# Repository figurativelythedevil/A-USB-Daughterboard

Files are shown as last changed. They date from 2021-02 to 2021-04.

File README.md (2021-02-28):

A work in progress.

This is a USB-C daughterboard for keyboards with a 4-port USB 2.0 hub on it (2 USB-A, 2 internal facing connectors on JST SR connectors), based around the Microchip USB2514 IC. 

Many thanks to:
* The [C3 Unified Daughterboard](https://github.com/ai03-2725/Unified-Daughterboard) project, form which this daughterboard was based off of 
* The [Nanohub Project](https://hackaday.io/project/20790-nanohub-tiny-usb-20-and-30-hubs) - the USB2514 schematic was partially referenced off of the 4-port USB 2.0 design 

This is available open-source under the CERN OHL-W license and uses the [Acheron library](https://github.com/AcheronProject/AcheronLibrary). 

This project has not been tested yet.

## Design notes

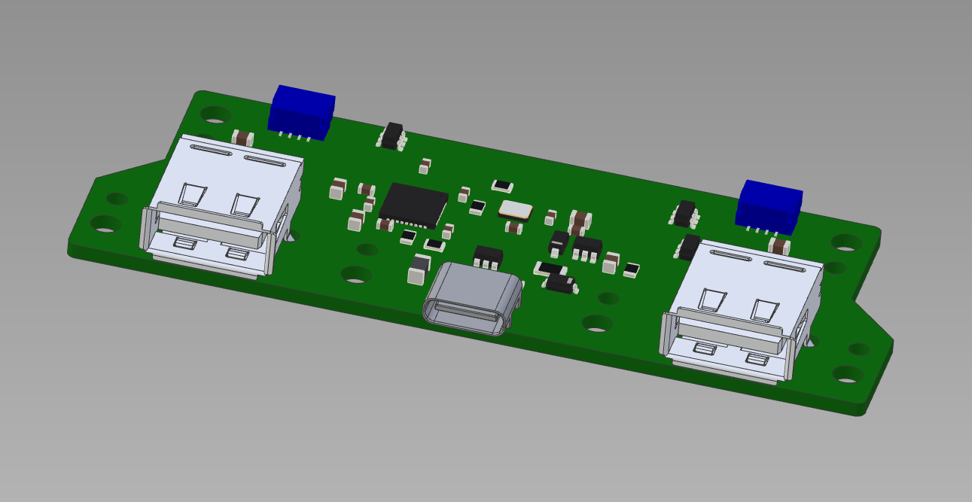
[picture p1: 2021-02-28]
3D-picture.PNG

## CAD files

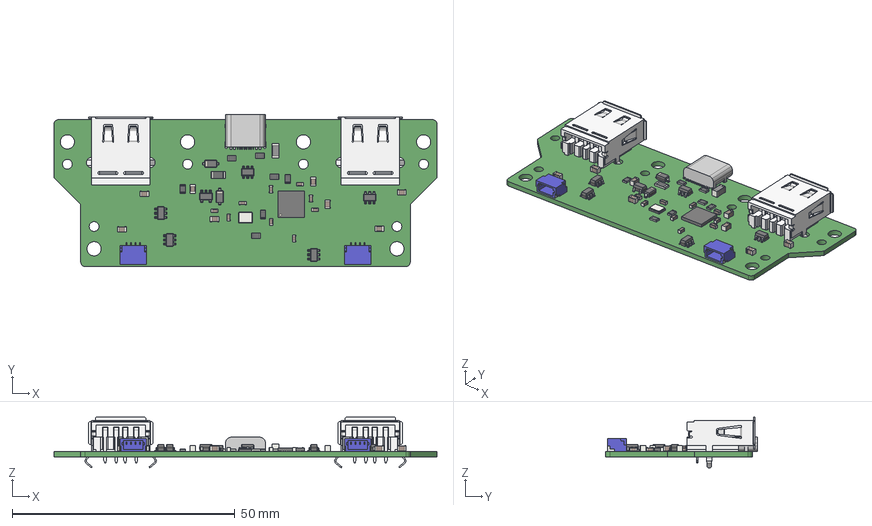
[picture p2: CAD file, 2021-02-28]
A-USB-daughterboard.stp
86.0 x 34.2 x 11.4 mm

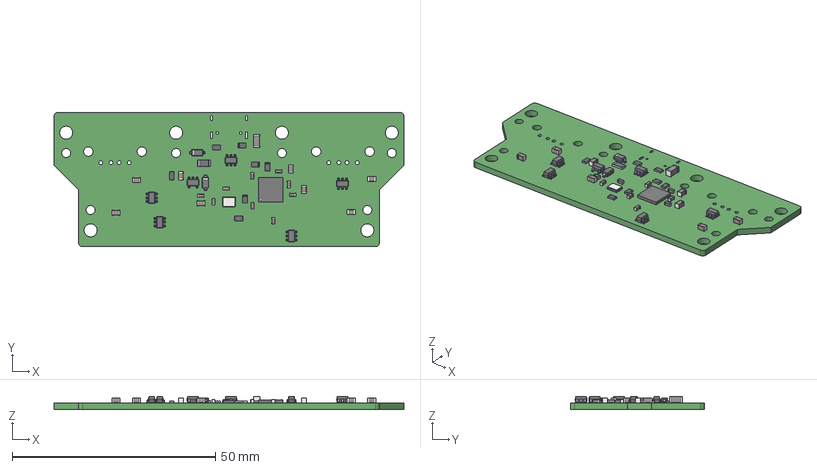
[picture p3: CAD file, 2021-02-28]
KiCAD files/USB-hub-daughterboard.step
86.0 x 33.0 x 3.25 mm

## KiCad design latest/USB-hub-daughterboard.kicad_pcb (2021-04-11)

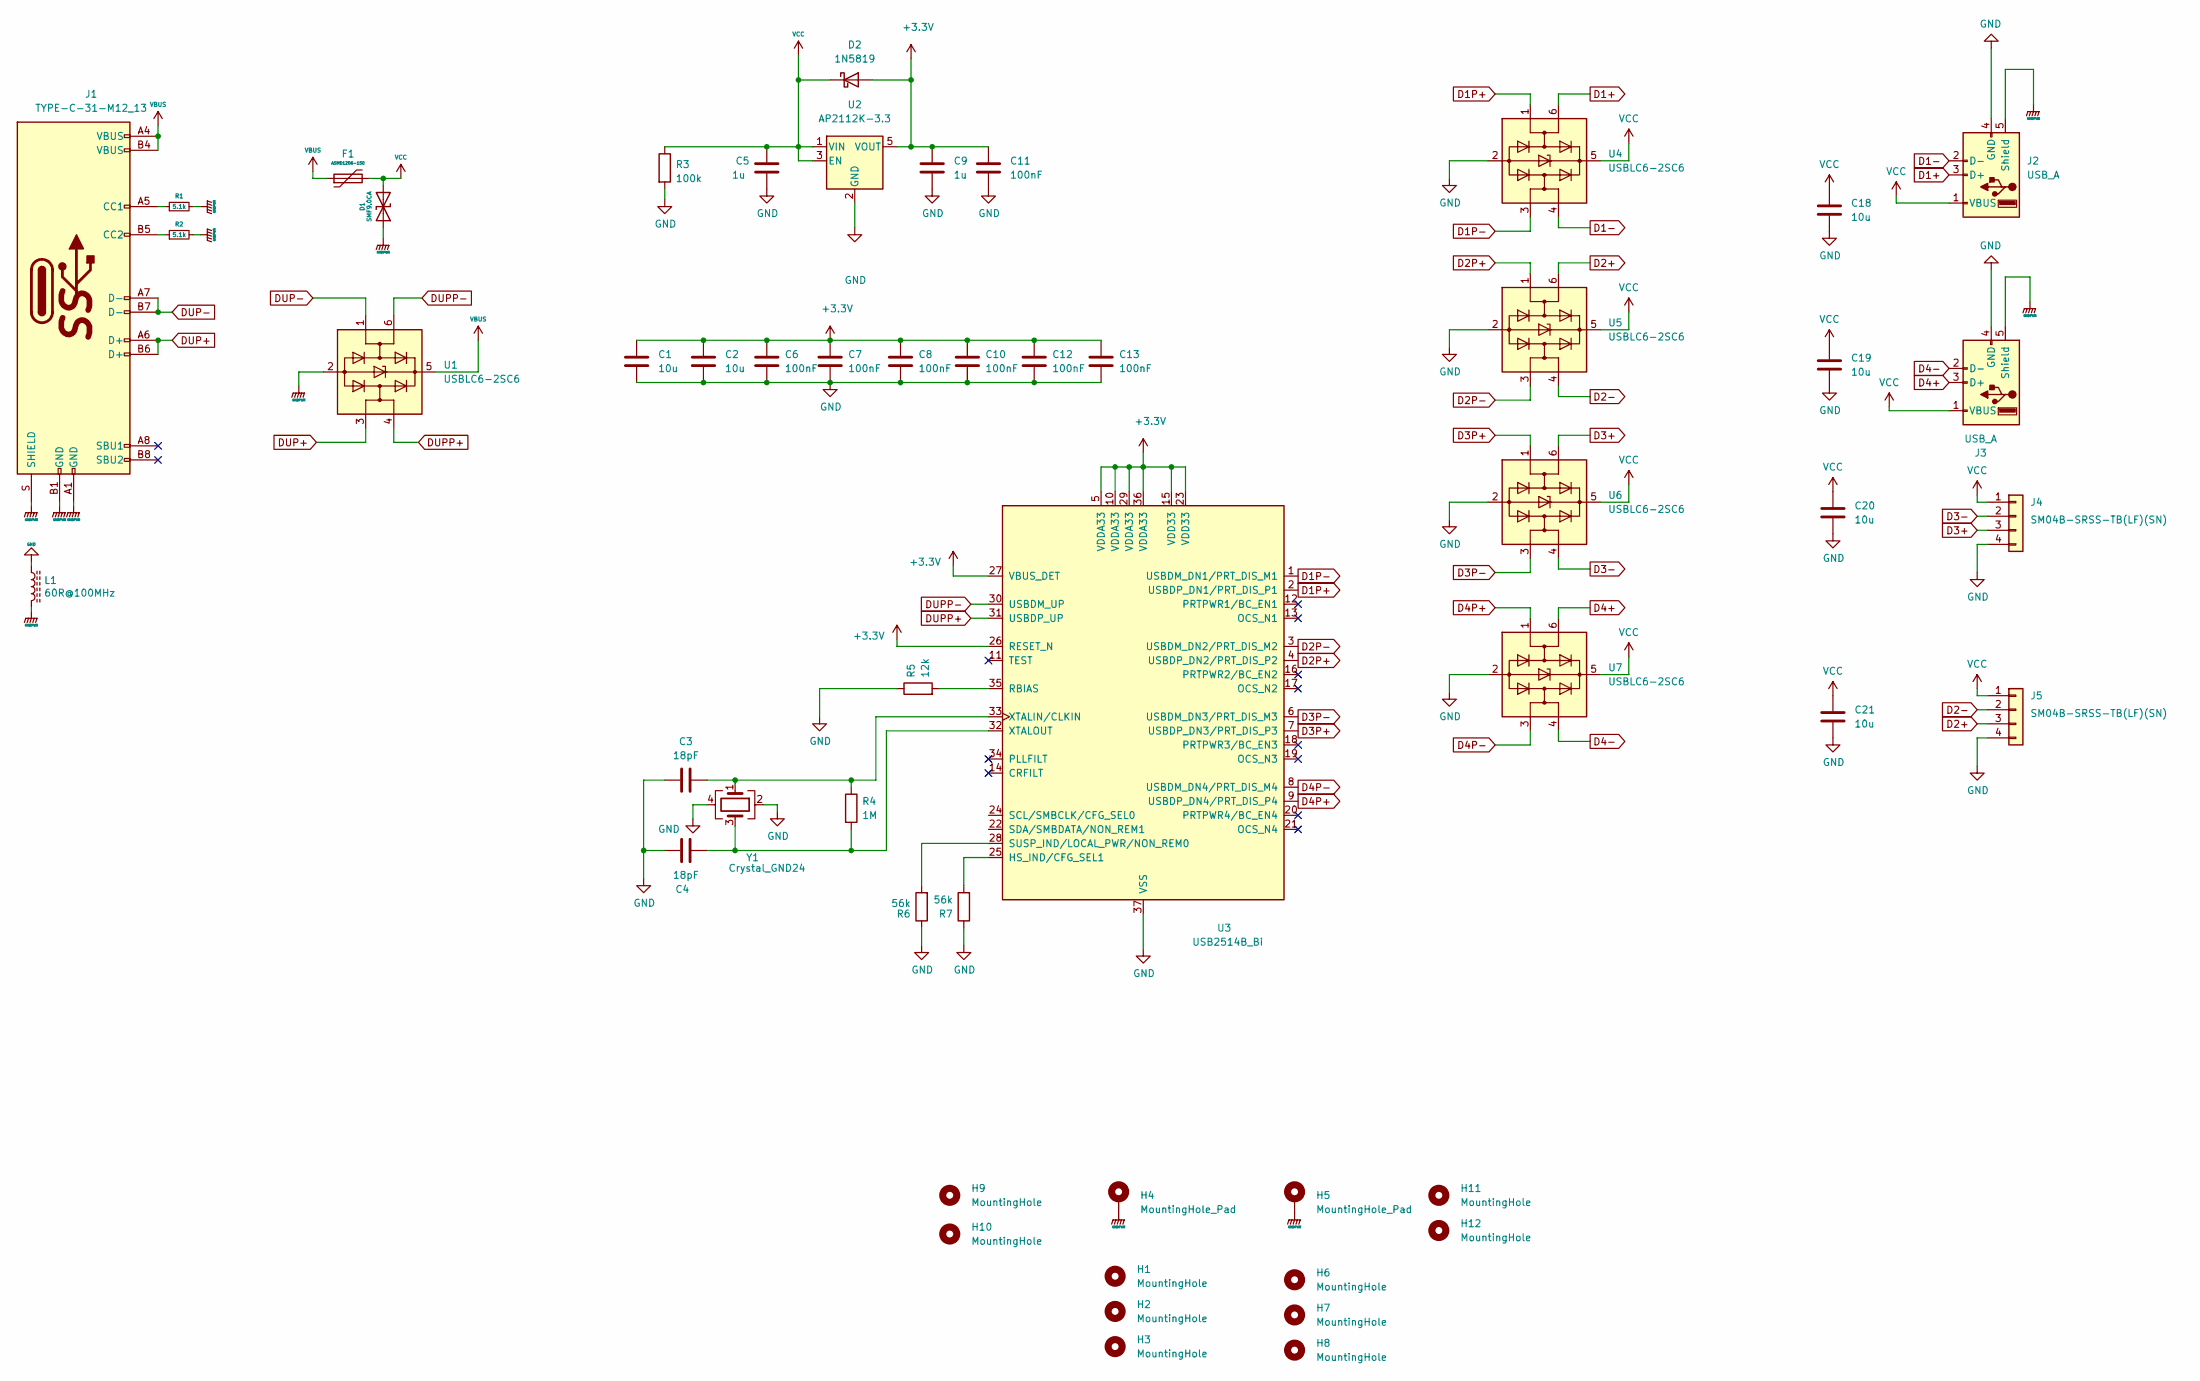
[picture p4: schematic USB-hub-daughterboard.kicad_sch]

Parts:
C1, C2, C18, C19, C20, C21: 10u; C_0805_2012Metric_Pad1.15x1.40mm_HandSolder
C3, C4: 18pF; C_0603_1608Metric_Pad1.05x0.95mm_HandSolder
C5, C9: 1u; C_0805_2012Metric_Pad1.15x1.40mm_HandSolder
C6, C7, C8, C10, C11, C12, C13: 100nF; C_0603_1608Metric_Pad1.05x0.95mm_HandSolder
D1: SMF9.0CA; D_SOD-123_Bidirectional; Manufacturer Part No SMF9.0CA; LCSC Part No C123799
D2: 1N5819; D_SOD-123
F1: ASMD1206-150; Fuse_1206_3216Metric; Manufacturer Part No ASMD1206-150; LCSC Part No C135342
H1, H2, H3, H9, H10: MountingHole; MountingHole_3.2mm_M3_ISO7380
H4: MountingHole_Pad; MountingHole_3.2mm_M3_ISO7380_Pad
H5: MountingHole_Pad; MountingHole_2.2mm_M2_ISO7380_Pad
H6, H7, H8, H11, H12: MountingHole; MountingHole_2.2mm_M2_ISO7380
J1: TYPE-C-31-M12_13; TYPE-C-31-M-12
J2, J3: USB_A; USB_A_Molex_67643_Horizontal
J4, J5: SM04B-SRSS-TB(LF)(SN); Manufacturer Part No SM04B-SRSS-TB(LF)(SN); LCSC Part No C160404
L1: 60R@100MHz; L_1206_3216Metric; Manufacturer Part No MLB3216-600P4A(f); LCSC Part No C33600
R1, R2: 5.1k; R_0805_2012Metric_Pad1.15x1.40mm_HandSolder
R3: 100k; R_0805_2012Metric_Pad1.15x1.40mm_HandSolder
R4: 1M; R_0805_2012Metric_Pad1.15x1.40mm_HandSolder
R5: 12k; R_0805_2012Metric_Pad1.15x1.40mm_HandSolder
R6, R7: 56k; R_0805_2012Metric_Pad1.15x1.40mm_HandSolder
U1, U4, U5, U6, U7: USBLC6-2SC6; SOT-23-6
U2: AP2112K-3.3; SOT-23-5
U3: USB2514B_Bi; QFN-36-1EP_6x6mm_P0.5mm_EP3.7x3.7mm
Y1: Crystal_GND24; Crystal_SMD_3225-4Pin_3.2x2.5mm_HandSoldering

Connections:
+3V3: C1.1, C2.1, C6.1, C7.1, C8.1, C9.1, C10.1, C11.1, C12.1, C13.1, D2.2 (A), U2.5 (VOUT), U3.5 (VDDA33), U3.10 (VDDA33), U3.15 (VDD33), U3.23 (VDD33), U3.26 (RESET_N), U3.27 (VBUS_DET), U3.29 (VDDA33), U3.36 (VDDA33)
D1+: J2.3 (D+), U4.6 (I/O1)
D1-: J2.2 (D-), U4.4 (I/O2)
D1P+: U3.2 (USBDP_DN1/PRT_DIS_P1), U4.1 (I/O1)
D1P-: U3.1 (USBDM_DN1/PRT_DIS_M1), U4.3 (I/O2)
D2+: J5.3, U5.6 (I/O1)
D2-: J5.2, U5.4 (I/O2)
D2P+: U3.4 (USBDP_DN2/PRT_DIS_P2), U5.1 (I/O1)
D2P-: U3.3 (USBDM_DN2/PRT_DIS_M2), U5.3 (I/O2)
D3+: J4.3, U6.6 (I/O1)
D3-: J4.2, U6.4 (I/O2)
D3P+: U3.7 (USBDP_DN3/PRT_DIS_P3), U6.1 (I/O1)
D3P-: U3.6 (USBDM_DN3/PRT_DIS_M3), U6.3 (I/O2)
D4+: J3.3 (D+), U7.6 (I/O1)
D4-: J3.2 (D-), U7.4 (I/O2)
D4P+: U3.9 (USBDP_DN4/PRT_DIS_P4), U7.1 (I/O1)
D4P-: U3.8 (USBDM_DN4/PRT_DIS_M4), U7.3 (I/O2)
DUP+: J1.A6 (D+), J1.B6 (D+), U1.3 (I/O2)
DUP-: J1.A7 (D-), J1.B7 (D-), U1.1 (I/O1)
DUPP+: U1.4 (I/O2), U3.31 (USBDP_UP)
DUPP-: U1.6 (I/O1), U3.30 (USBDM_UP)
GND: C1.2, C2.2, C3.1, C4.1, C5.2, C6.2, C7.2, C8.2, C9.2, C10.2, C11.2, C12.2, C13.2, C18.2, C19.2, C20.2, C21.2, J2.4 (GND), J3.4 (GND), J4.4, J5.4, L1.1, R3.2, R5.1, R6.1, R7.1, U2.2 (GND), U3.37 (VSS), U4.2 (GND), U5.2 (GND), U6.2 (GND), U7.2 (GND), Y1.2, Y1.4
GNDPWR: D1.1 (A1), H4.1, H5.1, J1.A1 (GND), J1.B1 (GND), J1.S (SHIELD), J2.5 (Shield), J3.5 (Shield), L1.2, R1.2, R2.2, U1.2 (GND)
unnamed: C3.2, R4.1, U3.33 (XTALIN/CLKIN), Y1.1
unnamed: C4.2, R4.2, U3.32 (XTALOUT), Y1.3
unnamed: J1.A5 (CC1), R1.1
unnamed: J1.B5 (CC2), R2.1
unnamed: R5.2, U3.35 (RBIAS)
unnamed: R6.2, U3.28 (SUSP_IND/LOCAL_PWR/NON_REM0)
unnamed: R7.2, U3.25 (HS_IND/CFG_SEL1)
VBUS: F1.1, J1.A4 (VBUS), J1.B4 (VBUS), U1.5 (VBUS)
VCC: C5.1, C18.1, C19.1, C20.1, C21.1, D1.2 (A2), D2.1 (K), F1.2, J2.1 (VBUS), J3.1 (VBUS), J4.1, J5.1, R3.1, U2.1 (VIN), U2.3 (EN), U4.5 (VBUS), U5.5 (VBUS), U6.5 (VBUS), U7.5 (VBUS)

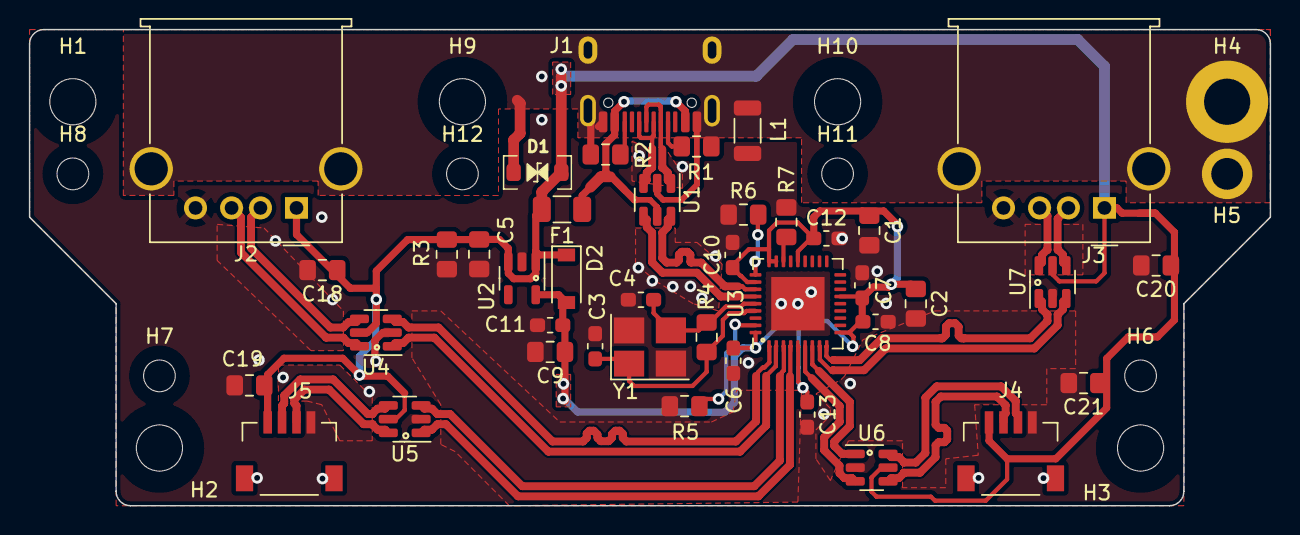
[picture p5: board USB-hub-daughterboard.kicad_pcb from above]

Board: 2 copper layers, 86.0 x 33.0 mm, 53 parts (0 on the bottom side), 32 nets.

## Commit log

2021-02-25 Work in progress updates
    [USB-hub-daughterboard.kicad_pcb, USB-hub-daughterboard.kicad_sch]
2021-02-28 More layout work
    [USB-hub-daughterboard.kicad_pcb, USB-hub-daughterboard.kicad_sch]
2021-02-28 Initial revision
    [USB-hub-daughterboard.kicad_pcb, USB-hub-daughterboard.kicad_sch]
2021-02-28 More work
    [A-USB-daughterboard.stp, USB-hub-daughterboard.kicad_pcb, USB-hub-daughterboard.step]
2021-02-28 Slightly improved routing, made PCB 1.2mm thick
    [A-USB-daughterboard.stp, USB-hub-daughterboard.kicad_pcb]
2021-04-11 Forked from Pylon for reference
    [USB-hub-daughterboard.kicad_pcb, USB-hub-daughterboard.kicad_sch]
